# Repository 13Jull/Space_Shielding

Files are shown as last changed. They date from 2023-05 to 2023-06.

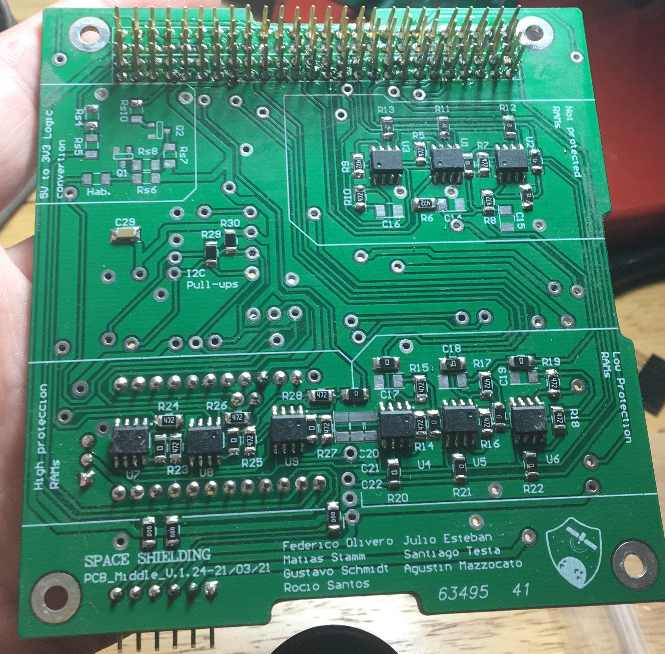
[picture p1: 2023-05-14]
PCBs/PCB_Middle/Final_Product_Bottom_PCB_Middle_for_testing.JPG

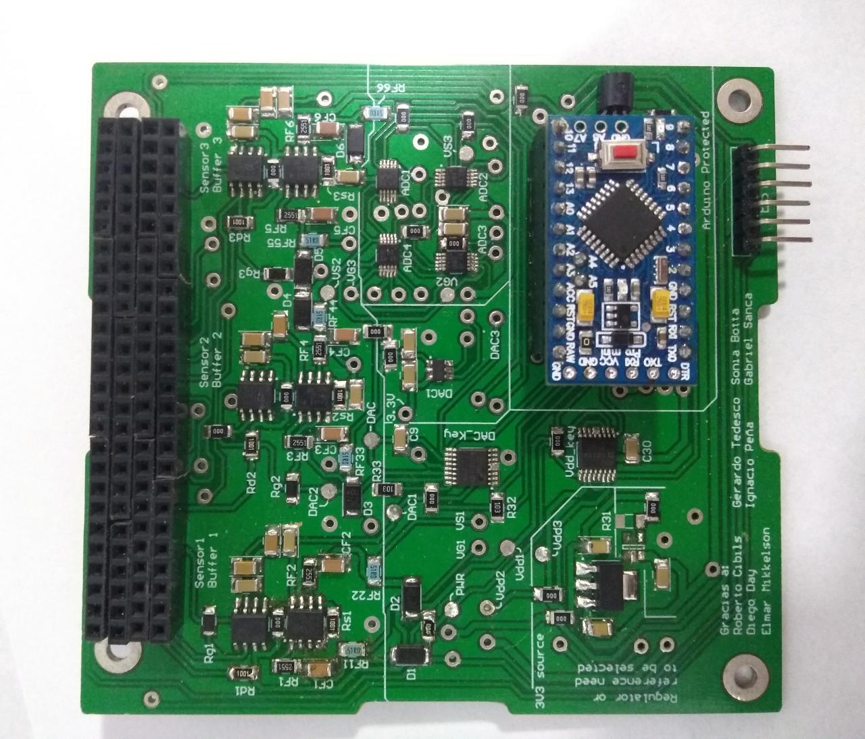
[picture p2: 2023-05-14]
PCBs/PCB_Middle/Final_Product_Top_PCB_Middle_for_testing.jpeg

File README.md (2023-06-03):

Mission Patch Space Shielding (2)

# Space_Shielding project
This git is for the Space Shielding project. Here you can find all the information that took us almost two years to generate, although a lot would change if we start again today. It was a lot of learning for us, and we hope this is useful for you. Thanks for visiting this git.

## Contents
  - Reports
  - PCBs (for now, only the Space Shielding part, we are working to add the rest of the PCBs of the payload)
  - Codes (Developed codes for the different MCUs)
  - Photos

## Work to be done:
   - [ ] Translate existing files from Spanish to English
   - [ ] Add PCB_Top and PCB_Bottom
   - [ ] Add STM32 Code
   - [ ] Add the MATLAB codes used for the analysis
   - [ ] Add experimental data
   - [ ] Add ANSYS and CAD simulation for shield
   - [ ] More photos of the complete process

## Space Shielding team
Federico Olivero, Santiago Testa, Agustín Mazzocato, Rocío Santos, Carolina Ibañez, Mateo Javier Carriere, Matias Stamm, Gustavo Schmidt, and Julio Esteban

**_Thanks to everyone who made this possible_**

   _This git is under development. Feel free to email me at julioesteban13@gmail.com if you have questions or need something you think I can provide._

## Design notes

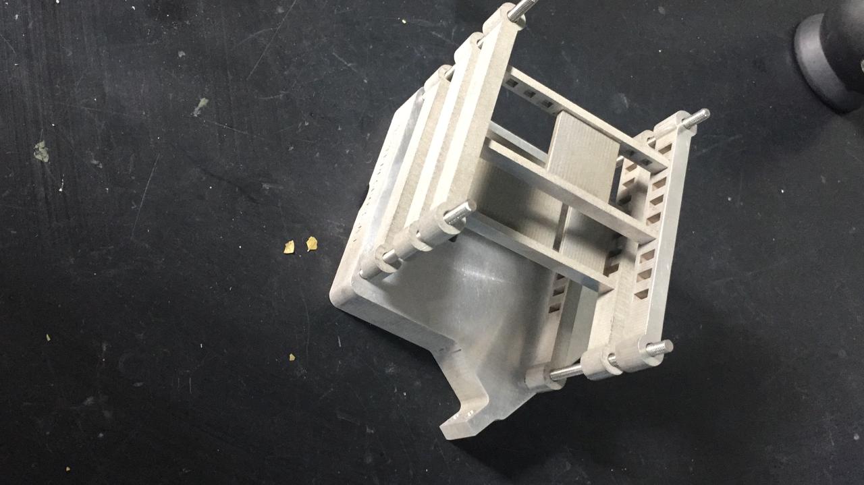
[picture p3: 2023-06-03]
Some Photos/WhatsApp Image 2020-10-21 at 9.06.05 AM.jpeg

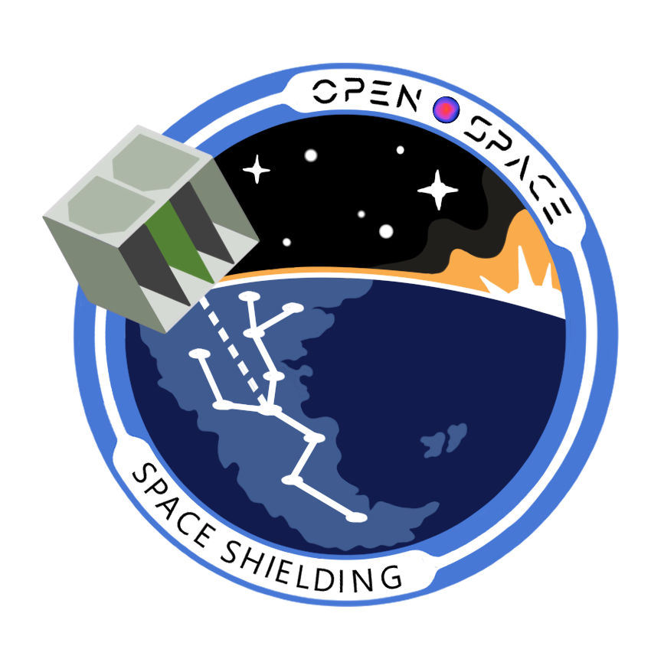
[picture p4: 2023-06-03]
Some Photos/Mission Patch Space Shielding (2).png

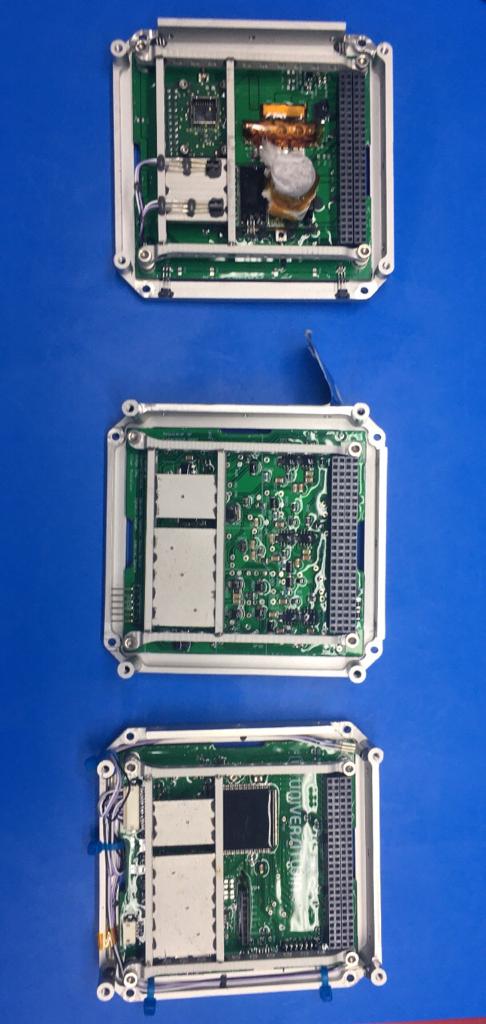
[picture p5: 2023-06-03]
Some Photos/WhatsApp Image 2023-06-02 at 10.47.30 PM.jpeg

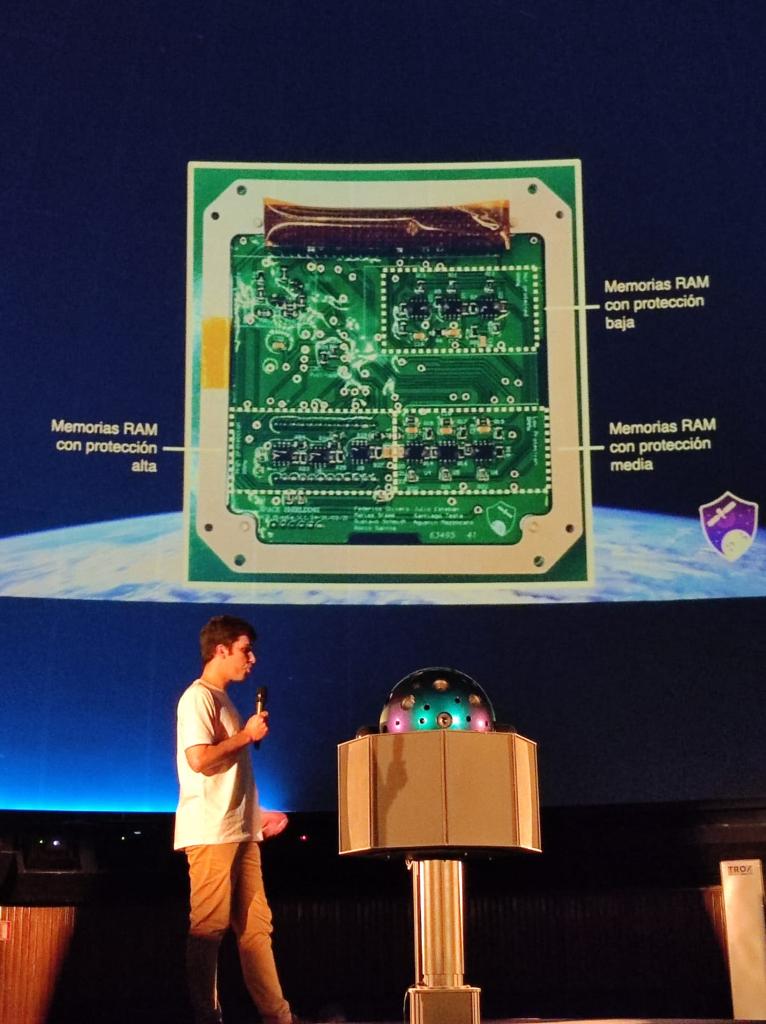
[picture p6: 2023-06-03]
Some Photos/WhatsApp Image 2023-06-02 at 10.56.20 PM.jpeg

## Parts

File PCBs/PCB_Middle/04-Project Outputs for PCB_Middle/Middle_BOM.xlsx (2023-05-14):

Comment | Description | Designator | Footprint | LibRef | Quantity | Supplier Part Number 1
ADS1115IDGST | 16-Bit ADC with Integrated Multiplexer, PGA, Comparator, Oscillator, and Reference, -40 to 125 degC, 10-pin SOP (DGS10), Green (RoHS & no Sb/Br) | ADC1, ADC2, ADC3, ADC_4 | TI-DGS10_N | ADS1115IDGST | 4 | 296-45221-1-ND
Llave2 | High Voltage Latch-Up Proof, Quad SPST Switches, -40 to 125 degC, 16-pin SOP (RU-16), Tube | ADG 1 | ADI-RU-16_N | ADG5412BRUZ | 1 | ADG5412BRUZ-ND
Llave1 | High Voltage Latch-Up Proof, Quad SPST Switches, -40 to 125 degC, 16-pin SOP (RU-16), Tube | ADG 5412 | ADI-RU-16_N | ADG5412BRUZ | 1 | ADG5412BRUZ-ND
Arduino_Pro_Mini |  | Arduino Protected | Arduino_Pro_Mini | Arduino_Pro_Mini | 1 | 1568-1055-ND
OPA2735AID | 0.05 uV/degC (max) Single-Supply CMOS Operational Amplifier, Zero-Drift Series, 2.7 to 12 V, -40 to 85 degC, 8-pin SOIC (D8), Green (RoHS & no Sb/Br) | Buffer 1, Buffer 2, Buffer 3 | TI-D8_N | OPA2735AID | 3 | 296-16770-5-ND
100pF | 1206 Capacitor | C1, C2, C3, C4, C5, C6, C7, C8, C9 | C1206 | C1206 | 9 | 399-8127-1-ND
1uF | 1206 Capacitor | C1T, C10T, C12T, C14T, C16T, C18T | C1206 | C1206 | 6 | 399-1255-1-ND
100nF | 1206 Capacitor | C2T, C11T, C13T, C15T, C17T, C19T, C20, C21, C22, C23, C30, C31 | C1206 | C1206 | 12 | 478-1556-1-ND
0.1uf | 1206 Capacitor | C10 | C1206 | C1206 | 1 | 478-1556-1-ND
22uF | 1206 Capacitor | CF1, CF2, CF3, CF4, CF5, CF6 | C1206 | C1206 | 6 | 490-4843-1-ND
10uF | 1206 Capacitor | Creg1, CReg2 | C1206 | C1206 | 2 | 478-3811-1-ND
MCP4725A0T-E/CH | 12-Bit Digital-to-Analog Converter with EEPROM Memory in SOT-23-6, 6-Pin SOT-23, Extended Temperature, Tape and Reel | DAC | SOT-23-CH6_N | MCP4725A0T-E/CH | 1 | MCP4725A0T-E/CHCT-ND
PC104 Stackable connector | Header_2x26_2.54mm | H1, H2 | SAMTEC_ESQ-126-39-G-D | SAMTEC_ESQ-126-39-G-D | 2 | SAM9323-ND
MMBT2222 | Transistor BJT NPN | Q1, Q2 | SOT95P240X114-3N | MMBT2222 | 2 | MMBT2222LT1GOSCT-ND
4k7 | 1206 Resistor | R1, R2, R3, R4, R5, R6, R7, R8, R9, R10, R11, R12, R13, R14, R15, R16, R17, R18 | R1206 | R1206 | 20 | 541-4.7KECT-ND
0 | 1206 Resistor | R19, R20, R21, R22, R23, R24 | R1206 | R1206 | 6 | 541-3033-1-ND
10k | 1206 Resistor | R25, R26, R27, R28, R30, R31, R32 | R1206 | R1206 | 7 | 541-CRCW120610K0JNTACT-ND
TBD | 1206 Resistor | R29 | R1206 | R1206 | 1
1k | 1206 Resistor 1% CMP2010A 1Watt 100ppm | Rd1, Rd2, Rd3, Rs1, Rs2, Rs3, Rs5, Rs6, Rs7, Rs8, Rs9 | R1206 | R1206 | 11 | 118-CMP1206-FX-1001ELFCT-ND
2k55 | 1206 Resistor | RF1, RF2, RF3, RF4, RF5, RF6 | R1206 | R1206 | 6 | 541-2.55KFCT-ND
10Meg | 1206 Resistor 1% CMP2010A 1Watt 100ppm | Rg1, Rg2, Rg3 | R1206 | R1206 | 3 | 541-10MECT-ND
2k | 1206 Resistor 1% CMP2010A 1Watt 100ppm | Rs4 | R1206 | R1206 | 1 | 541-2.00KFCT-ND
OPA735AID | 0.05 uV/degC (Max), Single-Supply CMOS Zero-Drift Series Operational Amplifier, 2.7 to 12 V, -40 to 85 degC, 8-pin SOIC (D8), Green (RoHS & no Sb/Br) | Sensor1, Sensor2, Sensor3 | TI-D8_N | OPA735AID | 3 | 296-17995-ND
ADR366WAUJZ-REEL7 | Low Power, Low Noise Voltage Reference with Sink / Source Capability, 3.3 V Output, 3.6 to 15 V Supply, Automotive, 5-pin SOT23 (UJ-5), Reel | SOURCE | ADI-UJ-5_M | CMP-0784-00514-1 | 1 | ADR366WAUJZ-REEL7CT-ND
DS18S20+ | 1-Wire Digital Thermometer, 3 to 5.5 V, -55 to 125 degC, 3-Pin TO-92, RoHS, Bulk | TEMP | MAXM-Q3-1 | CMP-2000-05212-1 | 1 | DS18S20+-ND
Header 6H | Header, 6-Pin, Right Angle | TEST | HDR1X6H | Header 6H | 1
23K256-E/SN | 256K, 32768x8-bit, 3.6V SPI Serial SRAM, 8-Pin SOIC 3.9mm, Extended Temperature | U1, U2, U3, U4, U5, U6, U7, U8, U9 | SOIC-SN8_L | 23K256-E/SN | 9 | 23K256-E/SN-ND
NCV1117ST33T3G | IC REG LINEAR 3.3V 1A SOT223 | U10 | FP-318H-MFG | CMP-07128-000021-1 | 1 | NCV1117ST33T3GOSCT-ND

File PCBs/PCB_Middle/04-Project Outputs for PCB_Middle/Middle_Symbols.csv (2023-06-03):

LIBRARYREFERENCE | FOOTPRINT1 | FOOTPRINT2 | FOOTPRINT3 | # INPUT CHANNELS | ANALOG VOLTAGE AV/DD(MAX)(V) | ANALOG VOLTAGE AV/DD(MIN)(V) | ARCHITECTURE | CHANNEL POLARITY | CISS TYP (PF) | CMRR(MIN)(DB) | CODE_IPC | CODE_JEDEC | COMMENT | COMPONENTLINK1DESCRIPTION | COMPONENTLINK1URL | COMPONENTLINK2DESCRIPTION | COMPONENTLINK2URL | COMPONENTLINK3DESCRIPTION | COMPONENTLINK3URL | COMPONENTLINK4DESCRIPTION | COMPONENTLINK4URL | COMPTYPE | CONFIGURATION | COSS TYP (PF) | CRSS TYP (PF) | DATASHEETVERSION | DIGITAL SUPPLY(MAX)(V) | DIGITAL SUPPLY(MIN)(V) | ECO-PLAN | GBW(TYP)(MHZ) | HIGH-RELIABILITY | ID MAX (A) | ID, IS (ON) | IIB(MAX)(PA) | INL(MAX)(+/-LSB) | INTERFACE | IQ PER CHANNEL(MAX)(MA) | IS OFF | MANUFACTURER | MOUNTING TECHNOLOGY | NUMBER OF CHANNELS | OFFSET DRIFT(TYP)(UV/C) | PACKAGE TYPE | PACKAGEDESCRIPTION | PACKAGEREFERENCE | PACKAGETOPMARKING | PACKAGEVERSION | PACKING | PARTNUMBER | PD MAX (W) | PINCOUNT | POWER DISSIPATION | POWERWISE | RATING | RESOLUTION(BITS) | ROHS | RON (OHMS) | SAMPLE RATE (MAX)(SPS) | SLEW RATE(TYP)(V/US)
23K256-E/SN | SOIC-SN8_N | SOIC-SN8_L | SOIC-SN8_M |  |  |  |  |  |  |  | SOIC127P600-8 | MS-012 |  | Manufacturer URL | http://www.microchip.com/ | Datasheet | http://ww1.microchip.com/downloads/en/DeviceDoc/22100D.pdf | Package Specification | http://www.microchip.com/stellent/groups/techpub_sg/documents/packagingspec/en012702.pdf |  |  |  |  |  |  | revD, Apr-2009 |  |  |  |  |  |  |  |  |  |  |  |  | Microchip | Surface Mount |  |  |  | 8-Lead Plastic Small Outline (SN) - Narrow, 3.90mm Body [SOIC] | SOIC-SN8 |  | revBB, Aug-2009 |  | 23K256-E/SN
2N7000 | ONSC-TO-92-3-29-11_AM_BL |  |  |  |  |  |  | N Channel | 60 |  |  |  |  | Manufacturer URL | http://www.onsemi.com/ | Datasheet | http://www.onsemi.com/pub_link/Collateral/2N7000-D.PDF | Package Specification | http://www.onsemi.cn/pub_link/Collateral/2N6426-D.PDF |  |  |  | Single | 25 | 5 | Rev. 8 |  |  |  |  |  | 0.2 |  |  |  |  |  |  | On Semiconductor | Through Hole |  |  | TO-92 | 3-Pin Transistor Outline, Body 4.825 x 3.685 mm, Pitch 1.27 mm | TO-92-3-29-11_AM_SL |  | Rev. AM | Bulk Box | 2N7000 | 0.35
ADG5412BRUZ | ADI-RU-16_N | ADI-RU-16_L | ADI-RU-16_M |  |  |  |  |  |  |  |  | MO-153AB |  | Manufacturer URL | http://www.analog.com/en/index.html | Datasheet | http://www.analog.com/static/imported-files/data_sheets/ADG5412_5413.pdf | Package Specification | http:/www.analog.com/static/imported-files/packages/36244347913743854010197452789RU16.pdf |  |  |  | SPST |  |  | Rev. A |  |  |  |  |  |  | 100pA, 100pA, 100pA, 100pA |  |  |  |  | 50pA, 50pA, 50pA, 50pA | Analog Devices | Surface Mount |  |  |  | 16-Pin Thin Shrink Small Outline Package, Body 5 x 4.4 mm, Pitch 0.65 mm | RU-16 |  | Nov-02 | Tube | ADG5412BRUZ |  |  | 1mW |  |  |  |  | 9
ADS1015QDGSRQ1 | TI-DGS10_N | TI-DGS10_L | TI-DGS10_M | 4 | 5.5 | 2 | Delta-Sigma |  |  |  |  | MO-153 |  | Manufacturer URL | http://www.ti.com/ | Datasheet | http://www.ti.com/general/docs/lit/getliterature.tsp?genericPartNumber=ADS1015-Q1&fileType=pdf | Package Specification | http://www.ti.com/lit/ml/mpds035b/mpds035b.pdf |  |  |  |  |  |  | SBAS511 | 5.5 | 2 | Green (RoHS & no Sb/Br) |  |  |  |  |  | 0.5 | Serial I2C |  |  | Texas Instruments | Surface Mount |  |  |  | 10-Pin Plastic Small Outline, Body 3 x 3 mm, Pitch 0.5 mm | DGS10 |  | 4073272/C, 02/2004 |  | ADS1015QDGSRQ1 |  |  |  |  |  | 12 |  |  | 3.3k
Arduino_Pro_Mini | Arduino |  |  |  |  |  |  |  |  |  |  |  | *
C1206 | C1206 |  |  |  |  |  |  |  |  |  |  |  | 10nF
LM74CIM-3 | M08A_N | M08A_L | M08A_M |  |  |  |  |  |  |  | SOIC127P600-8 | MS-012-AA |  | Manufacturer URL | http://www.national.com/ | LM74 Datasheet | http://www.national.com/ds/LM/LM74.pdf | LM74 Web Page | http://www.national.com/pf/LM/LM74.html | M08A Package Page | http://www.national.com/packaging/folders/m08a.html | Temp Sensor IC |  |  |  | May-2005 |  |  |  |  | Y |  |  |  |  |  |  |  | National Semiconductor |  |  |  |  | SOIC Narrow, 4.9 x 3.9 x 1.45mm, 8 Lead, 1.27mm Pitch | M08A | NSZXTT*LM74*CIM3 | revM, May-2009 |  | LM74CIM-3 |  | 8 |  | N |  |  | N
MCP4725A0T-E/CH | SOT-23-CH6_N | SOT-23-CH6_L | SOT-23-CH6_M |  |  |  |  |  |  |  | SOT26A-6 |  |  | Manufacturer URL | http://www.microchip.com/ | Datasheet | http://ww1.microchip.com/downloads/en/DeviceDoc/22039d.pdf | Package Specification | http://www.microchip.com/stellent/groups/techpub_sg/documents/packagingspec/en012702.pdf |  |  |  |  |  |  | revD, Jun-2009 |  |  |  |  |  |  |  |  |  |  |  |  | Microchip | Surface Mount |  |  |  | 6-Lead Plastic Small Outline Transistor (CH) [SOT-23] | SOT-23-CH6 |  | revBB, Aug-2009 |  | MCP4725A0T-E/CH
OPA2735AID | TI-D8_N | TI-D8_L | TI-D8_M |  |  |  |  |  |  | 115 |  | MS-012 |  | Manufacturer URL | http://www.ti.com/ | Datasheet | http://www.ti.com/lit/ds/symlink/opa2735.pdf | Package Specification | http://www.ti.com/litv/pdf/msoi002j |  |  |  |  |  |  | SBOS282B |  |  | Green (RoHS & no Sb/Br) | 1.6 |  |  |  | 200 |  |  | 0.75 |  | Texas Instruments | Surface Mount | 2 | 0.01 |  | 8-Pin Plastic Small Outline, Body 4.9 x 3.9 mm, Pitch 1.27 mm | D8 |  | 4040047-3/M, 06/2011 | TUBE | OPA2735AID |  |  |  |  | Catalog |  |  |  |  | 1.5
OPA735AID | TI-D8_N | TI-D8_L | TI-D8_M |  |  |  |  |  |  | 115 |  | MS-012 |  | Manufacturer URL | http://www.ti.com/ | Datasheet | http://www.ti.com/lit/ds/symlink/opa735.pdf | Package Specification | http://www.ti.com/litv/pdf/msoi002j |  |  |  |  |  |  | SBOS282B |  |  | Green (RoHS & no Sb/Br) | 1.6 |  |  |  | 200 |  |  | 0.75 |  | Texas Instruments | Surface Mount | 1 | 0.01 |  | 8-Pin Plastic Small Outline, Body 4.9 x 3.9 mm, Pitch 1.27 mm | D8 |  | 4040047-3/M, 06/2011 | TUBE | OPA735AID |  |  |  |  | Catalog |  |  |  |  | 1.5
R1206 | R1206
SAMTEC_ESQ-126-39-G-D | SAMTEC_ESQ-126-39-G-D |  |  |  |  |  |  |  |  |  |  |  | PC104 Stackable connector
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

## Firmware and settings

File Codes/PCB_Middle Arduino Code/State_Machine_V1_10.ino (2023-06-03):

////////////////////////////////////////////////////////////////////////////////
//State Machine V.1.10
//
//Maquina de estados para Open Space
//Programa a usar con arduino pro mini 5V/16MHz
//
//Fecha: 22/01/21
//Edito: JE.
//
//Notas: - Probada con STM32. Queda enviando datos validados, faltan codigos y
//         formato final de datos, junto con comandos.
//
//Siguientes pasos: -
//
//V.1.00: -Simple maquina de estados -> Cambio de estado muy simple funcionando
//V.1.01: -Maquina de estado con la lectura de las curvas de transistores.
//V.1.02: -Se agrega el CRC y se comenta mejor
//V.1.03: -Se le agrega el CRC a los datos enviados
//V.1.04: -Se agregar el control de la maquina de estados via mensajes 
//V.1.05: -Faltan agregar maquinas de estados pero se guardan datos en SD
//         SD a traves del STM y se leen y analizan los datos con MATLAB.
//         Se agrega el envio del tiempo. -> FALLA GRAVE AL ENVIAR MAS DE 
//         4 PUNTOS. EL STRING ES MUY LARGO Y EL ARDUINO ENLOQUECE.
//V.1.06: -Se intenta solucionar el problema grave de enviar varios puntos
//V.1.07: -Problema de V.1.06 solucionado. Se emprolija para primer testeo 
//         general el domingo 19/9/21
//V.1.08: -Se agregan las funciones de verificacion I2C y temp interna. 
//V.1.09: -Se emprolijan los mensajes de salida y se agrega la entrada 
//         de configuraciones
//V.1.10  -Se agregan los dos sensores de temp 
///////////////////////////////////////////////////////////////////////////////


/////////// Definitions///////////

#define Samples 10
#define Points 9
#define DAC_Setting_Time 200 //Express in ms
#define ONE_WIRE_MIDDLE 8
#define ONE_WIRE_NADIR 10
#define Resend_times 4
#define Resend_times_data 4
#define Time_out 1000
#define DAC_Max_Voltage 3000

/*     -START Debug selection-      */
///////////////////////// Debug selection ///////////////////////////////
//                                                                     //
//Select the Debug uncommenting the first line.                        //
//                                                                     //
/////////////////////////////////////////////////////////////////////////

//General Debug
//#define Debug
#ifdef Debug
 #define Debug(x)  Serial.print (x)
 #define Debugln(x)  Serial.println (x)
#else
 #define Debug(x)
 #define Debugln(x)
#endif

//General Debug
//#define Debug_temp 
#ifdef Debug_temp 
 #define DebugT(x)  Serial.print (x)
 #define DebugTln(x)  Serial.println (x)
#else
 #define DebugT(x)
 #define DebugTln(x)
#endif

//ADC lecture Debug
//#define Debug_ADC
#ifdef Debug_ADC
  #define Debug_adc(x)  Serial.print (x)
  #define Debugln_adc(x)  Serial.println (x)
#else
  #define Debug_adc(x)
  #define Debugln_adc(x)
#endif


//Statistics Debug
//#define Debug_Statitics
#ifdef Debug_Statitics
  #define Debug_Stats(x)  Serial.print (x)
  #define Debugln_Stats(x)  Serial.println (x)
#else
  #define Debug_Stats(x)
  #define Debugln_Stats(x)
#endif

//Debug Send Protocol
//#define DebugSP
#ifdef DebugSP
 #define DebugSP(x)  Serial.print (x)
 #define DebugSPln(x)  Serial.println (x)
#else
 #define DebugSP(x)
 #define DebugSPln(x)
#endif
//Debug Error detecting
//#define DebugErrorDet
#ifdef DebugErrorDet
 #define DebugErrorDet(x)  Serial.print (x)
 #define DebugErrorDetln(x)  Serial.println (x)
 #define DebugErrorDetHex(x) Serial.print(x,HEX)
#else
 #define DebugErrorDet(x)
 #define DebugErrorDetln(x)
 #define DebugErrorDetHex(x)
#endif

/*     -END Debug selection-      */

/*     -START Setting parameters-      */
///////////////////////// Setting parameters ////////////////////////////
//                                                                     //
//General parameters initialization and setting.                       //
//                                                                     //
/////////////////////////////////////////////////////////////////////////

///////////Libraries///////////

#include <Adafruit_ADS1X15.h>
#include <Adafruit_MCP4725.h> // MCP4725 library from adafruit
#include <OneWire.h>
#include <DallasTemperature.h>
#include <stdio.h>      /* printf */
#include <stdlib.h>     /* strtol */
#include <avr/wdt.h>    /*Watchdog*/
#include "CRC8.h"
#include "CRC.h"
//////////////////////////////

///////////Initializations///////////
//CRC
CRC8 crc;
// Temperature sensor
OneWire oneWire(ONE_WIRE_MIDDLE);
OneWire oneWire_Nadir(ONE_WIRE_NADIR);
// Pass our oneWire reference to Dallas Temperature. 
DallasTemperature sensors(&oneWire);
DallasTemperature sensors_N(&oneWire_Nadir);
//DAC inicialization
Adafruit_MCP4725 MCP4725; 
//ADC inicialization
Adafruit_ADS1115 ads1;  /* Use this for the 16-bit version */
Adafruit_ADS1115 ads2;  /* Use this for the 16-bit version */
Adafruit_ADS1115 ads3;  /* Use this for the 16-bit version */
Adafruit_ADS1115 ads4;  /* Use this for the 16-bit version */
//Adafruit_ADS1015 ads;     /* Use this for the 12-bit version */
///////////////////////////////

///////////Declaracion de estados///////////
enum State_enum {START_DATASET, SEND_DATA, WAITING, CHECK_STATUS, ERROR_HANDLING, TEST};
uint8_t state=WAITING;
////////////////////////////////////////////

///////////Variables globales//////////////
char inputString[100];        // Input buffer
bool stringComplete = false;  // Message received flag
char Message[100];        // Input buffer
uint16_t Buffer[14][Points];
static bool ledState= false;
volatile bool SendOk = false; 
volatile int ErrorCode = 0; 
///////////////////////////////////////////

///////////Declaracion de funciones//////////////
int Read_adc_1(short Counter_Punto,short ADC_name);
void Mosfet_Curve(int Counter_adc);
void DAC(uint32_t MCP4725_value);
int Send(int adc);
bool Send_Command(String Packet);
int Add_CRC(String Packet);
void software_reboot(){asm volatile("jmp 0");}
int control_temp_interno(void);
int I2C_Verification(void);
///////////////////////////////////////////

/*     -END Setting parameters-      */


/*     -START Setup-      */
/////////////////////////////// Setup ///////////////////////////////////
//                                                                     //
//Device initialization                                                //
//                                                                     //
/////////////////////////////////////////////////////////////////////////



void setup() {
  // Serial initialization  
  Serial.begin(9600);
  
  // I/O ports
  pinMode(LED_BUILTIN, OUTPUT);
  
  ///Apertura llaves de habilitacion
  pinMode(4,OUTPUT);//KEY FOR VDD
  digitalWrite(4,HIGH);
  pinMode(7,OUTPUT);//KEY FOR DAC
  digitalWrite(7,HIGH);  
  
  pinMode(5,OUTPUT);//KEY FOR VDD
  digitalWrite(5,HIGH);
  pinMode(3,OUTPUT);//KEY FOR DAC
  digitalWrite(3,HIGH);  
  
  pinMode(2,OUTPUT);//KEY FOR VDD
  digitalWrite(2,HIGH);
  pinMode(6,OUTPUT);//KEY FOR DAC
  digitalWrite(6,HIGH); 
  
  //ADCs
  ads1.setGain(GAIN_TWOTHIRDS);  // 2/3x gain +/- 6.144V  1 bit = 3mV      0.1875mV (default)
  ads2.setGain(GAIN_TWOTHIRDS);  // 2/3x gain +/- 6.144V  1 bit = 3mV      0.1875mV (default)
  ads3.setGain(GAIN_TWOTHIRDS);  // 2/3x gain +/- 6.144V  1 bit = 3mV      0.1875mV (default)
  ads4.setGain(GAIN_TWOTHIRDS);  // 2/3x gain +/- 6.144V  1 bit = 3mV      0.1875mV (default)
  ads1.begin(0x49);
  ads2.begin(0x48);
  ads3.begin(0x4B);
  ads4.begin(0x4A);
  
  //DAC
  MCP4725.begin(0x64);
  
  //Temp. Sensor
  sensors.begin();  //Temp Sensor
  sensors_N.begin();  //Temp Sensor

  //CRC Setting
  crc.setPolynome(0x97);
  
  //Delay de seguridad
  delay(1000);
}
/*     -END Setup-      */


/*     -START main-      */
///////////////////////////////// Main //////////////////////////////////
//                                                                     //
//Main. Here is contained the state machine and the call to the        //
//functions.                                                           //
//                                                                     //
/////////////////////////////////////////////////////////////////////////

void loop() {
int Message_Counter=0;
static int Counter_adc=1;
String DATA="";
///////// START MESSAGES INPUT ////////////

  if (stringComplete) {    
        Serial.println();
        Serial.println(inputString);  
         Message_Counter=0;                

       //START MESSAGE VALIDATION
       if(CRC_Validation()==1){
        
            while((inputString[Message_Counter]!='\r') & (Message_Counter < 98)){  //Cambiar '1' por '\r'
             
              Message[Message_Counter]=inputString[Message_Counter];            
              Serial.println(Message[Message_Counter]);
              Message_Counter++;
            }     
        Serial.println("\n\nMessage validated!!\n\n");         
          
         }else{
          
          Serial.println("\n\nMessage with errors!!\n\n");
         }
      
       
       //for (short i=0;i<6;i++){
       //  Serial.print("\nMessage: ");
       //  Serial.print(Message[i]); 
       //  Serial.print("- i : ");
       // Serial.print(i);   
       // }
        
        
        //////////////////////////
                
        //Restart input string    
        for (short i=0;i<98;i++){
          inputString[i]=0;
        }
        
        stringComplete=false;
        /////////////////////
  }  
///////// END MESSAGES INPUT ////////////
 

//STATE MACHINE
 
  switch(state){
    
    case WAITING:
    state=CHECK_STATUS;
    if(strcmp(Message, "Start")==0){
        state=START_DATASET; 
      }else if(strcmp(Message, "Status")==0){
        state=CHECK_STATUS;
      }
    break;
    
    case CHECK_STATUS:
   // if(Send_Command((String)"Status Report")){
    //  if(Send_Command((String)"-I2C Ver.:")){
          DATA.concat(I2C_Verification());
          Serial.print(Add_CRC(DATA));
          DATA="";
         // if(Send_Command((String)"-Internal Temp.:")){            
            DATA.concat(control_temp_interno());
            Serial.print(Add_CRC(DATA));
            DATA="";
          //  if(Send_Command((String)"-Board Temp.:")){
              sensors.requestTemperatures(); // Send the command to get temperatures.         
              DATA.concat(sensors.getTempCByIndex(0)*1000);
              Serial.print("TEMP:");
              Serial.print(Add_CRC(DATA));
              DATA="";
              sensors_N.requestTemperatures(); // Send the command to get temperatures.         
              DATA.concat(sensors_N.getTempCByIndex(0)*1000);
              Serial.print("TEMP_N:");
              Serial.print(Add_CRC(DATA));
              DATA="";
           /* 
            }else{
              state=ERROR_HANDLING;       
              ErrorCode=1; //ERROR IN COMMUNICATION. Too many attemps.
            }
          }else{
            state=ERROR_HANDLING;       
            ErrorCode=1; //ERROR IN COMMUNICATION. Too many attemps.
          } 
        }else{
          state=ERROR_HANDLING;       
          ErrorCode=1; //ERROR IN COMMUNICATION. Too many attemps.    
        }
    }else{
      state=ERROR_HANDLING;       
      ErrorCode=1; //ERROR IN COMMUNICATION. Too many attemps.
    }
      */
    Send_Command((String)"END Status");
    break;
    
 
    
    case START_DATASET:
      if(Counter_adc<4){
       if(Send_Command((String)"STARTING")==0){          
          SendOk=false;
          Mosfet_Curve(Counter_adc);       
          Serial.println("END");      
          state=SEND_DATA;         
        }else{
          state=ERROR_HANDLING;       
          ErrorCode=1; //ERROR IN COMMUNICATION. Too many attemps.
        }            
      }else{
        Counter_adc=1;
        state=WAITING;
      }
      
    break;
    
    case SEND_DATA:
    digitalWrite(LED_BUILTIN, HIGH);         
    if(Send_Command((String)"SENDING DATA")==0){
        SendOk=false;
    
        if(Send(Counter_adc)==1){ //Look if there has been an error
          state=ERROR_HANDLING;       
          ErrorCode=1; //ERROR IN COMMUNICATION. Too many attemps.
        }else{
          Counter_adc++; 
        state=START_DATASET;
        }        
    }else{
      state=ERROR_HANDLING;       
      ErrorCode=1; //ERROR IN COMMUNICATION. Too many attemps.
    }    
    digitalWrite(LED_BUILTIN, LOW);     
    break;
    
    case ERROR_HANDLING:
    Send_Command((String)"ERROR! Error code:");
    DATA.concat(ErrorCode);
    Serial.println(Add_CRC(DATA));    
    DATA="";
    Send_Command((String)"ERROR! Restarting ...");
    delay(5000);
    software_reboot();
    break;
    
    case TEST:
    break;
    
  }

  //Clean Message    
  for (short i=0;i<98;i++){
          Message[i]=0;
        }
  //Serial.print(state);

}
/*     -END Main-      */


/*     -START Serial event-      */
///////////////////////////// Serial Event //////////////////////////////
//                                                                     //
//Arduino serial event. This executes every time the main loops ends.  //
//                                                                     //
/////////////////////////////////////////////////////////////////////////

void serialEvent() {
  static int CharCounter=0;
 
    while (Serial.available()) {
    // get the new byte:
    char inChar = (char)Serial.read();
    Serial.print(inChar);
    // add it to the inputString:
    inputString [CharCounter]= inChar;
    CharCounter++;
    
    // if the incoming character is a newline, set a flag so the main loop can
    // do something about it:
    if ((inChar == '\n') or (CharCounter>250)){
      CharCounter=0;  
      stringComplete = true;
      //Serial.print(inputString);
    }
  } 
}
/*     -END Serial Event-      */

/*     -START Mosfet curve reading-      */
/////////////////////// Mosfet curve reading ////////////////////////////
//                                                                     //
//Mosfet Vgs Vs. Id curve calculation. Measures of the 3 transistors   //
//are made. Mean and Std. Dev. are calculated in a number of samples   //
//define by "Samples" Constant.                                        //
/////////////////////////////////////////////////////////////////////////
void Mosfet_Curve(int Counter_adc){
  int c=0;
uint16_t MCP4725_value = 0;
uint16_t Tx_Flag = 0;
String DATA="";
  
    for (int i=0;i<Points;i++){
      //Serial.print(i);
      DAC(i*(DAC_Max_Voltage/Points));
      
      DATA.concat(i);
      Serial.print(DATA);      
      DebugSPln("\n///MOSFET CURVE///");
      DebugSP("DATA String: ");
      DebugSPln(DATA);
      DebugSP("DATA CRC: ");
      DebugSPln(Add_CRC(DATA));
      Serial.write(13);
      Serial.println(Add_CRC(DATA));  
      DATA="";
                
      Read_adc_1(i,Counter_adc);
       // Save Temperature Middle
       sensors.requestTemperatures(); // Send the command to get temperatures.
       float tempC = sensors.getTempCByIndex(0);     
       Buffer[12][i] =((tempC*1000)); 
       DebugT("Temp:");
       DebugTln((int16_t) (tempC*1000));

       // Save Temperature Nadir
       sensors_N.requestTemperatures(); // Send the command to get temperatures.
       tempC = sensors_N.getTempCByIndex(0);
       Buffer[13][i] =((tempC*1000)); 
       DebugT("Temp_N:");
       DebugTln((int16_t) (tempC*1000));
       
    }
    DAC(0);
    //Serial.write(255);
     while (Serial.available() <= 1);
      if(Serial.read()=="\n"){
        ledState = !ledState;
        digitalWrite(LED_BUILTIN, ledState);    
      }
      
    
  
  
}
/*     -END Mosfet curve reading-      */

/*     -START Data sending-      */
////////////////////// Data sending ///////////////////////////////////
//                                                                   //
//This function sends data via UART. It sends the Buffer data with   //
//some sync parameters incorporated.                                 // 
//                                                                   //
///////////////////////////////////////////////////////////////////////

int Send(int adc){
int Tries_counter=0;
bool Error_Flag=0;
int Counter_A=0,Counter_B=0,Counter_Send=1;
static int Status=0;
String DATA="";
DebugSPln("\n///SEND DATA///");
  Serial.write(13);
  while (Serial.available() <= 0);
  if(Serial.read()==10){
    ledState = !ledState;
    digitalWrite(LED_BUILTIN, ledState);    
  }

  Counter_B=0;

  while ((Counter_B<=13) and (Error_Flag==0)){
    while (Counter_Send<=(Points/3)){      
        //Serial.print(Counter_Send);
        DATA.concat(adc);
        DATA.concat(",");
        //Serial.print(Counter_B+1);
        DATA.concat(Counter_B+1); 
        DATA.concat(","); 
        DATA.concat(Counter_Send); 
        //DATA=concat(char(adc);
          for (Counter_A=((Counter_Send-1)*3);Counter_A<((Counter_Send)*3);Counter_A++){
            
             //Serial.print(Buffer[Counter_B][Counter_A]>>8);
              //DATA.concat(Buffer[Counter_B][Counter_A]>>8);
             //Serial.print(Buffer[Counter_B][Counter_A]);
              DATA.concat(",");
              DATA.concat((uint16_t)Buffer[Counter_B][Counter_A]);
              //DATA.concat((uint16_t)Buffer[Counter_B][Counter_A]*0.0001875); //Select this one for decimal format.
              
          }
        DebugSP("DATA String: ");
        DebugSPln(DATA);
        DebugSP("DATA CRC: ");
        DebugSPln(Add_CRC(DATA));
        Serial.print(DATA);        
        Serial.write(13);
        Serial.println(Add_CRC(DATA));        
        DATA=""; 
    
      while (Serial.available() <= 0);
  
      Status=Serial.read();
       DebugSP("Status: ");
      DebugSPln(Status);
      if(Status==10){
        ledState = !ledState;
        digitalWrite(LED_BUILTIN, ledState);    
        Counter_Send++;
        Tries_counter=0;
      }else{
        Tries_counter++;
        
        DebugSP("\nResend counter: ");
        DebugSPln(Tries_counter);
      } 
       
      if(Tries_counter>Resend_times_data){
      Error_Flag=1;
      }
      
    }
    Counter_Send=1;
    Counter_B++;    
  }  
  if (Error_Flag==0){
    return 0;    
  }else{
    DebugSP("\n\n-> COMMUNICATION FAILURE! Too many tries.\n\n");
    return 1;
  }

}
/*     -END Data sending-      */





/*     -START DAC Setting-      */
////////////////////// DAC setting /////////////////////////////////
//                                                                //
// This function returns set the DAC value                        //
//                                                                //
//-Subfunction of "Mosfet curve reading"                          //
////////////////////////////////////////////////////////////////////
void DAC(uint32_t MCP4725_value) {
    
    float MCP4725_expected_output;
    
     // MCP4725_expected_output = (5.0/4096.0) * MCP4725_value;
      MCP4725.setVoltage(MCP4725_value, false);
      
      delay(DAC_Setting_Time);
            
      //Serial.print("MCP4725 Value: ");
      //Serial.print(MCP4725_value);      
      //Serial.print("\tExpected Voltage: ");
      //Serial.println(MCP4725_expected_output,3); 
}
/*     -END DAC Setting-      */


/*     -START ADC Reading-      */
//////////////////////ADC reading//////////////////////////////////////
//                                                                   //
// This function returns Mean and Variance of the ADC lecture under  //
//the number of samples define in "#define Samples X".               //
//                                                                   //
//-Subfunction of "Mosfet curve reading"                             //
///////////////////////////////////////////////////////////////////////
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

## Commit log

2023-05-14 Add files via upload
    First Commit of PCB_Middle from Space Sielding to Open Space
    [Middle_Arduino.SchDoc, Middle_B2B.SchDoc, Middle_BOM.xlsx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]
2023-05-20 Add files via upload
    Program used in the Arduino Pro-Mini on PCB Middle
2023-06-03 Reorganize folders
    [Middle_Arduino.SchDoc, Middle_B2B.SchDoc, Middle_BOM.xlsx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]
